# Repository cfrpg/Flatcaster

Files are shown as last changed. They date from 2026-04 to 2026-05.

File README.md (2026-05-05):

# Flatcaster

纯 PCB 实现的电容触摸吉他项目。

基于 AT32F435 主控，板载 AT-Link 下载器。采用 MAX98357A 功放输出，支持自校准电容矩阵触摸，可独立控制 6 根琴弦的拨动和 6 个品位，实现完整的弹奏体验。音色采用 Karplus-Strong 物理建模和 [Unreal Instruments](https://sfzinstruments.github.io/guitars/standard_guitar/) 的采样音源。包含网页上位机程序。

演示视频：[Bilibili](https://www.bilibili.com/video/BV1TAoMBCENc)

## 特性

- 纯 PCB 吉他结构
- AT32F435 主控 + 板载 AT-Link 下载器
- MAX98357A 功放输出
- 自校准电容矩阵触摸（6 根弦 + 6 个品位）
- Karplus-Strong 物理建模音色
- Unreal Instruments - Standard Guitar 音源
- 网页上位机程序

## 操作
### 基本操作
打开开关，LED红灯常亮，之后变为蓝色闪烁即可正常演奏。红色闪烁表示电池电量不足，请及时充电。

使用电位器调节音量。左侧6*7触摸区域为品位区，右侧长条触摸为拨弦区。

按**B**键切换模式。

### 演奏模式
开机后默认为演奏模式，LED为蓝色或绿色闪烁。

#### 校准触摸
如果触摸不灵，可以**长按A键**3秒以上松开，LED闪烁3次，完成触摸校准。

#### 切换音色
**短按A键**松开切换音色，LED蓝色闪烁为K-S音色，绿色闪烁为Unreal Instruments采样音源。

### 设置模式
在演奏模式下按**B**键进入设置模式，此时LED变为红色常亮。

设置完成后再次按**B**键使设置生效返回演奏模式。

#### 调整变调夹和移调

在品位区选择需要移动的半音数，**6弦1品**为移动**0个半音**，每增加一品**半音数+1**，每向上一条弦**半音数+6**。

按住的品位后，**拨动1弦**设置为移调数，**拨动6弦**设置为变调夹位置。

**拨动3弦或4弦**恢复初始设置。

LED闪烁3次表示设置生效，但重新开机后会恢复默认设置。

**eg：** 设置移调为2，变调夹为3，此时空弦变为原本的3品，1品变为原本的6品（1品+变调夹3+移调2）。

#### 保存参数

在设置模式下，**长按A键**3秒以上松开，LED闪烁5次，将设置保存到flash中，下次开机会保留当前的设置。

### 使用网页端上位机
下载src/Flatcaster.html到本地，使用USB线连接计算机，浏览器打开Flatcaster.html，点击连接串口，选择对应的串口连接。

### 常见问题

- 使用电池供电时可能会出现触摸不灵敏的情况，多次重新校准无效的情况下，可以尝试右手接触背面金属部分（如USB插座外壳或扬声器外壳），或连接USB线使用。

## 项目结构

```bash
Flatcaster/
├── doc/                # AT32引脚分配与仿真文件
├── pcb/                # 硬件设计
├── src/
│   ├── v0.1/           # AT32F435 固件源码
│   └── Flatcaster.html # 网页上位机
└── ...

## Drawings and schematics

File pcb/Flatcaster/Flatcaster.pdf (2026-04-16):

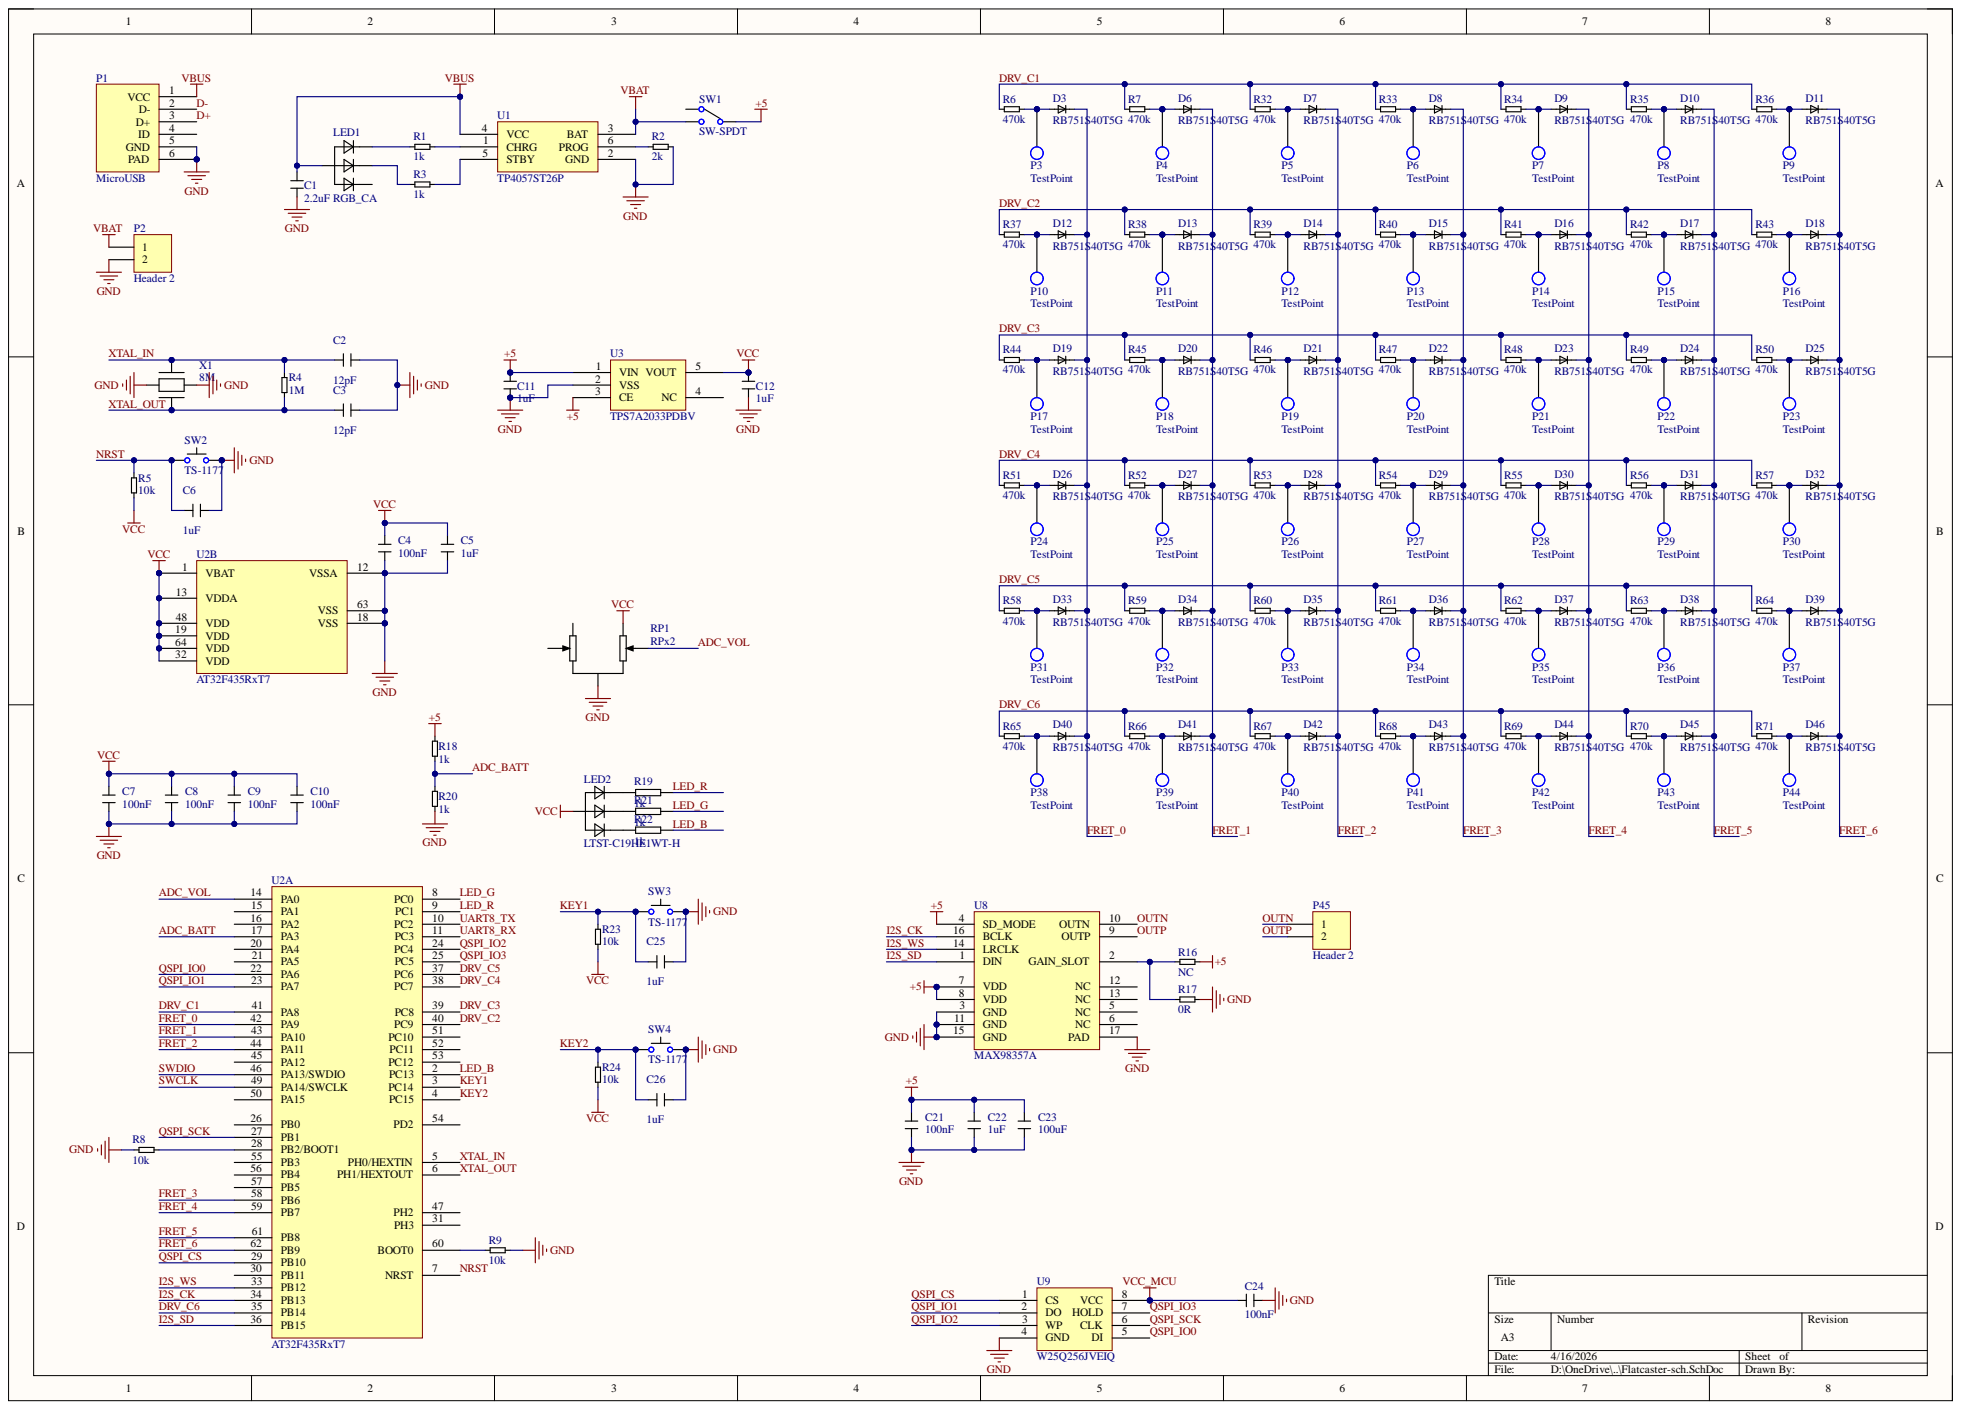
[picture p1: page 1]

VSS 2

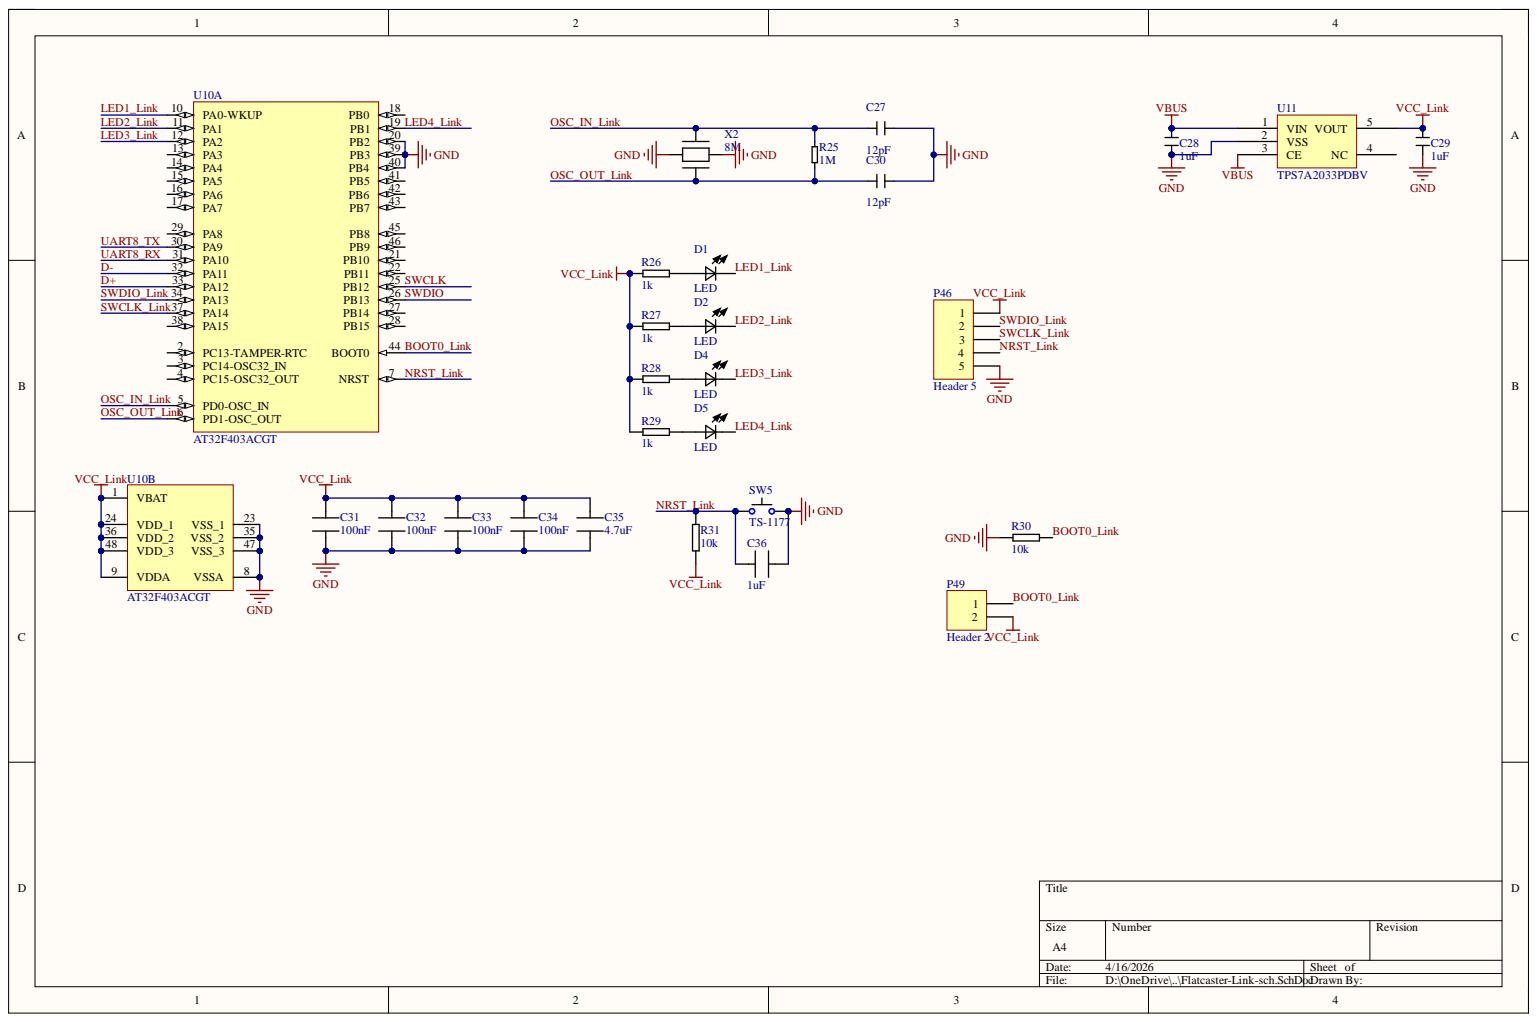
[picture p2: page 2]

3 6 | 3 5
4 8 | 4 7

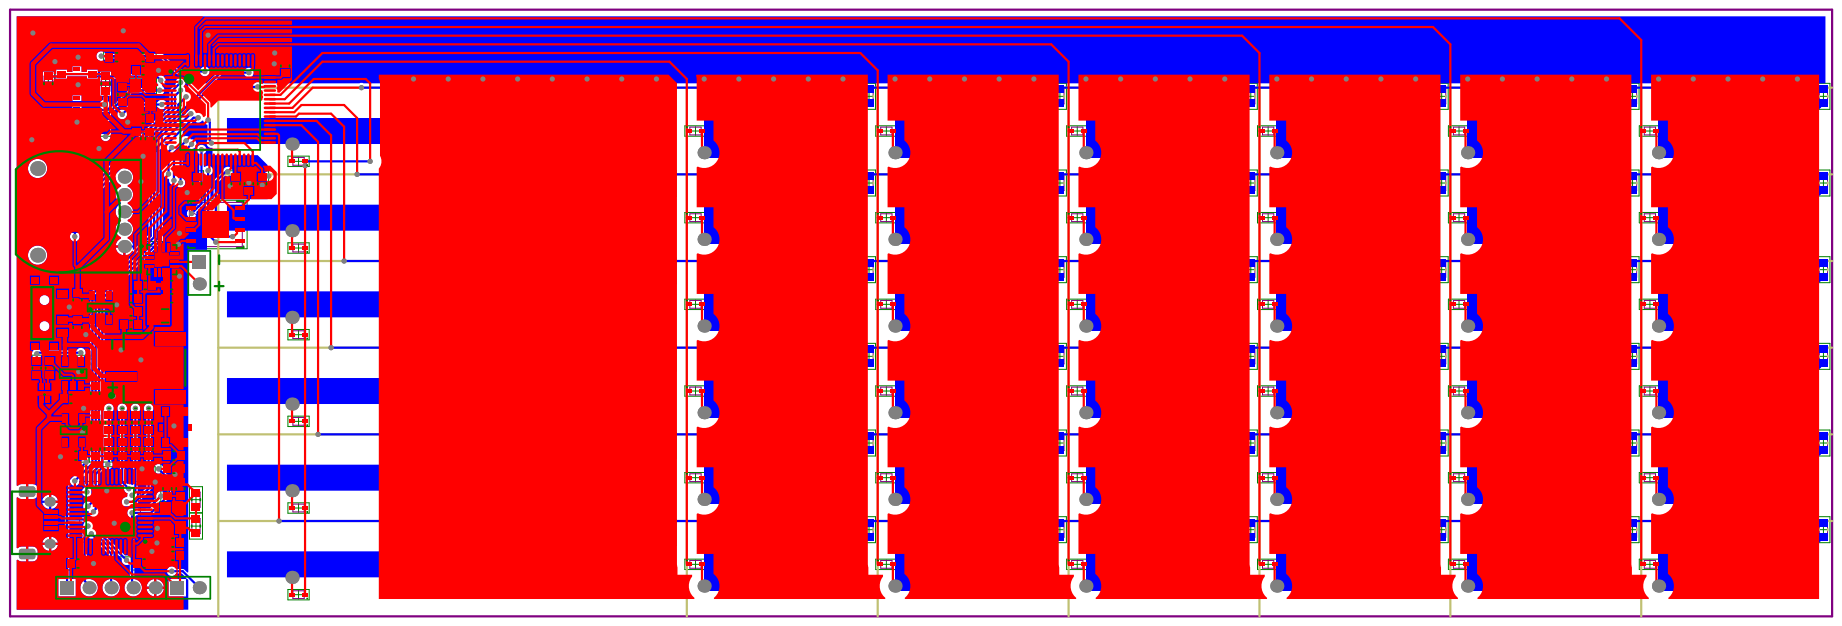
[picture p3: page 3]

Comment | Description | Designator | Footprint | LibRef | Quantity
2.2uF | | C1 | 0603-Cap | Cap | 1
12pF | | C2, C3, C27, C30 | 0603-Cap | Cap | 4
100nF | | C4, C7, C8, C9, C10, C21, C24, C31, C32, C33, C34 | 0603-Cap | Cap | 11
1uF | | C5, C6, C11, C12, C22, C25, C26, C28, C29, C36 | 0603-Cap | Cap | 10
100uF | | C23 | 1206-C | Cap | 1
4.7uF | | C35 | 0603-Cap | Cap | 1
LED | | D1, D2, D4, D5 | 0603-1 | LED | 4
RB751S40T5G | | D3, D6, D7, D8, D9, D10, D11, D12, D13, D14, D15, D16, D17, D18, D19, D20, D21, D22, D23, D24, D25, D26, D27, D28, D29, D30, D31, D32, D33, D34, D35, D36, D37, D38, D39, D40, D41, D42, D43, D44, D45, D46 | SOD-523 | Diode | 42
RGB_CA | | LED1 | RGB1.6*1.6 | RGB_CA | 1
LTST-C19HE1WT-H | C427425 | LED2 | RGB1.6*1.6 | RGB_CA | 1
MicroUSB | | P1 | MicroUSB | MicroUSB | 1
Header 2 | Header, 2-Pin | P2 | SH2.0 2P | Header 2 | 1
TestPoint | | P3, P4, P5, P6, P7, P8, P9, P10, P11, P12, P13, P14, P15, P16, P17, P18, P19, P20, P21, P22, P23, P24, P25, P26, P27, P28, P29, P30, P31, P32, P33, P34, P35, P36, P37, P38, P39, P40, P41, P42, P43, P44 | TestPoint | TestPoint | 42
Header 2 | Header, 2-Pin | P45, P49 | HDR1X2 | Header 2 | 2
Header 5 | Header, 5-Pin | P46 | HDR1X5 | Header 5 | 1
1k | | R1, R3, R18, R19, R20, R21, R22, R26, R27, R28, R29 | 0603 | Res | 11
2k | | R2 | 0603 | Res | 1
1M | | R4, R25 | 0603 | Res | 2
10k | | R5, R8, R9, R23, R24, R30, R31 | 0603 | Res | 7
470k | | R6, R7, R32, R33, R34, R35, R36, R37, R38, R39, R40, R41, R42, R43, R44, R45, R46, R47, R48, R49, R50, R51, R52, R53, R54, R55, R56, R57, R58, R59, R60, R61, R62, R63, R64, R65, R66, R67, R68, R69, R70, R71 | 0603 | Res | 42
NC | | R16 | 0603 | Res | 1
0R | | R17 | 0603 | Res | 1
RPx2 | | RP1 | RK10J | RPx2 | 1
SW-SPDT | C514014 | SW1 | TA-3524A-A1 | SW-SPDT | 1
TS-1177 | C561512 | SW2, SW3, SW4, SW5 | BTN3*3 | Btn | 4
TP4057ST26P | | U1 | SOT236 | TP4057ST26P | 1
AT32F435RxT7 | | U2 | LQFP-64 | AT32F435RxT7 | 1
TPS7A2033PDBV | | U3, U11 | SOT23-5 | ME6211 | 2
MAX98357A | | U8 | QFN16-0.5-1.1PAD | MAX98357A | 1
W25Q256JVEIQ | | U9 | WPDFN-8-6x5 | W25QxxxVE/A | 1
AT32F403ACGT | | U10 | STM-LQFP48_N | STM32F103CBT6 | 1
8M | C2682774 | X1, X2 | XTAL-3225-4P | XTAL-4LEAD | 2

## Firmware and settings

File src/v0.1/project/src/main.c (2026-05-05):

#include <stdio.h>
#include "sys.h"
#include "sys_config.h"
#include "delay.h"
#include "debug_usart.h"
#include "timer.h"
#include "led.h"
#include "parameter.h"
#include "pptlink.h"
#include "max98357a.h"
#include "signalGen.h"
#include "ks_engine.h"
#include "touch.h"
#include "midi.h"
#include "adc.h"
#include "norflash.h"
#include "instrument_data.h"
#include "mathHelper.h"
#include "spl_engine.h"
#include "keys.h"

#define STATE_PLAY	0
#define STATE_CALI	1
#define STATE_SET	2

void show_logo(void);

volatile u32 timecnt[4];

float freq_table[6][7];
u8 note_table[6][7];

KS_Engine my_guitar;
SPL_Engine spl_guitar;

s32 *capoPos;
s32 *fertShift;

float volume=0;
u8 low_batt=0;

u8 adc_ch=0;

u8 source=0;



u8 state=0;


void set_LED(void)
{
	if(low_batt==1)
	{
		LEDSetPattern(LED_2Hz,LED_OFF,LED_OFF);
	}
	else
	{
		if(state==STATE_PLAY)
		{
			if(source==0)
				LEDSetPattern(LED_OFF,LED_OFF,LED_1Hz);
			else
				LEDSetPattern(LED_OFF,LED_1Hz,LED_OFF);
		}
		if(state==STATE_SET)
		{
			LEDSetPattern(LED_ON,LED_OFF,LED_OFF);
		}
		
	}
}

void update_fert(void)
{
	for(u8 i=0;i<6;i++)
	{
		s32 idx=guitar_empty_string[i]+*capoPos;
		note_table[i][0]=idx;		
		for(u8 j=1;j<7;j++)
		{
			u8 real_fert=6-j+*fertShift+1;
			note_table[i][j]=idx+real_fert;			
		}
	}
	for(u8 i=0;i<6;i++)
	{
		for(u8 j=0;j<7;j++)
		{
			freq_table[i][j]=midi_frequencies[note_table[i][j]];
		}
	}	
}

int main(void)
{  
	SystemConfigInit();
	DelayInit(288000000);
	DebugUSARTInit(2000000);
	MainClockInit();
	ParamInit();
	
	// Init hardware drivers
	LEDInit();
	LEDSetRGB(0,1,1);
	LEDSetPattern(LED_OFF,LED_OFF,LED_1Hz);
	KeysInit();
	
	ADCInit();
	TouchInit();
	MAX98357AInit();
	FlashInit();	
	FlashXIPInit();
	
	// Init software modules
	ks_init(&my_guitar,48000);
	SPL_Init(&spl_guitar,&UI_guitar);
	u32 cnt=0;	
	u8 output=0;

	
	
	// Init freq table	
	capoPos=ParamGetFromName("CAPO_POS");
	fertShift=ParamGetFromName("FERT_SHIFT");
	update_fert();
	
	// Check vol
	ADCStartChannel(adc_ch);
	
	// Calibration
	LED_R=0;
	TouchScan();
	delay_ms(1000);
	TouchSetRef();
	LED_R=1;
	show_logo();
	
//	while(1);
	
	while(1)
	{
		// 10Hz update
		if(timecnt[0]>=10000)
		{
			timecnt[0]=0;
			LEDUpdate();
			if(adc_ch==0)
			{
				// vol data
				u16 vol=ADCReadOut()>>4;
				volume=vol*1.0f/256;
				adc_ch=3;
				
			}
			else if(adc_ch==3)
			{
				// batt data
				float volt=ADCReadVolt()*2;
				if(low_batt==0 && volt<3.68f)
				{
					low_batt=1;
					set_LED();
				}
				if(low_batt==1 && volt>3.68f)
				{
					low_batt=0;
					set_LED();
				}
				adc_ch=0;
				
			}
			ADCStartChannel(adc_ch);
			printf("FERT:%d,%d\r\n",*capoPos,*fertShift);
			
			// check keys
			KeysUpdate();
			if((KeyStatus[0]&0x01)==0)
			{
				if((KeyStatus[0])==0xFFFFFFFE)
				{	
					if(state==STATE_PLAY)
					{
						TouchSetRef();					
						LEDFlash(3);
					}
					else if(state==STATE_SET)
					{
						ParamWrite();
						LEDFlash(5);
					}
					
				}
				else if((KeyStatus[0]&0x1E)==0x1E)
				{
					if(state==STATE_PLAY)
					{
						source^=1;
						set_LED();
					}
					else if(state==STATE_SET)
					{
						
					}
					
				}			
			}
			
			
		}
		// 50Hz update
		if(timecnt[1]>=2000)
		{
			timecnt[1]=0;
			
			if(output==0)
			{
				printf("DATA:");
				for(u32 i=0;i<6;i++)
				{
					for(u32 j=0;j<8;j++)
					{					
						printf("%d,",touch.rawData[i][j]);					
					}
				}
			}
			else
			{
				printf("REF:");
				for(u32 i=0;i<6;i++)
				{
					for(u32 j=0;j<8;j++)
					{					
						printf("%d,",touch.refData[i][j]);					
					}
				}
			}			
			printf("\r\n");
			output^=1;
		}
		// 1000Hz update
		if(timecnt[2]>=100)
		{
			timecnt[2]=0;
			// get input
			TouchGetKey();
			
			if(state==STATE_PLAY)
			{
				// trigger note
				for(u8 str=0;str<6;str++)
				{
					if((touch.stringState[str]&0xFF)==0xF)
					{
						u8 note=note_table[str][touch.stringFert[str]];
						if(source==0)
						{
							stop_string_soft(&my_guitar.strings[str]);
							trig_note(&my_guitar,str,midi_frequencies[note],0.992f,0.2f);
						}
						else
						{
							SPL_Trig_note(&spl_guitar,str,note);
						}
						
						printf("TRIG:%d,%d,%d\r\n",str,touch.stringFert[str]==0?0:7-touch.stringFert[str],note);
					}
				}
				
				if(audioState.data_required!=0)
				{
					u32 pos=0;
					
					if(audioState.data_required==2)
						pos=I2S_BUF_SIZE;
					if(source==0)
					{
						for(u32 i=0;i<I2S_BUF_SIZE;i+=2)
						{
							float out=0;
							for(u32 j=0;j<6;j++)
							{
								out+=(update_string(&my_guitar.strings[j])*32768.0f)/6;
							}
							audioState.buff[i+pos]=(s16)(out*volume);
							audioState.buff[i+pos+1]=audioState.buff[i+pos];
						}
					}
					else
					{
						SPL_UpdateBuff(&spl_guitar);
						for(u32 i=0;i<I2S_BUF_SIZE;i+=2)
						{
							float out=0;
							for(u32 j=0;j<6;j++)
							{
								if(spl_guitar.strings[j].active>=0)
								{
									out+=((float)spl_guitar.strings[j].buff[i/2]);
								}						
							}
							out=Clampf(out/2*volume,-32767,32767);
							audioState.buff[i+pos]=(s16)(out*volume);
							audioState.buff[i+pos+1]=audioState.buff[i+pos];
						}
					}
					audioState.data_required=0;
				}
				if((KeyStatus[1]&0xFF)==0x0F)
				{
					state=STATE_SET;
					memset(audioState.buff,0,sizeof(audioState.buff));
					set_LED();
				}
			}
			else if(state==STATE_SET)
			{				
				u32 shift=0;
				// set capo & shift
				for(u8 str=5;str>=2;str--)
				{
					if(touch.stringFert[str]!=0)
					{
						shift=(5-str)*6+(6-touch.stringFert[str]);
						break;
					}
				}
				
				if((touch.stringState[0]&0x3F)==1)
				{
					// set capo
					*capoPos=shift;
					LEDFlash(3);
				}
				else if((touch.stringState[5]&0x3F)==1)
				{
					// set shift
					*fertShift=shift;
					LEDFlash(3);
				}
				else if(((touch.stringState[3]&0x3F)==1)||((touch.stringState[2]&0x3F)==1))
				{
					//reset
					*capoPos=0;
					*fertShift=0;
					LEDFlash(3);
				}
				
				if((KeyStatus[1]&0xFF)==0x0F)
				{
					state=STATE_PLAY;
					update_fert();
					set_LED();
				}
				
			}			
//			printf("%d\r\n",timecnt[2]);
		}
		// Slow work, 1Hz
		if(timecnt[3]>=100000)
		{
			timecnt[3]=0;
			
			if(debug_cmd_ready == 1)
			{
				//ppt link
				DebugUSARTGetCmd();
				AnalyzePkg(debug_cmd_buff, debug_cmd_length);
				debug_cmd_ready=0;
			}			
		}		
	}
}

void TMR1_BRK_TMR9_IRQHandler(void)
{
	u8 i;
	if(tmr_interrupt_flag_get(TMR9,TMR_OVF_FLAG)!=RESET)
	{
		tmr_flag_clear(TMR9,TMR_OVF_FLAG);
		for(i=0;i<4;i++)
		{
			timecnt[i]++;
		}
	}
}

void show_logo(void)
{	
	printf("___________.__          __                          __                \r\n");
	printf("\\_   _____/|  | _____ _/  |_  ____ _____    _______/  |_  ___________ \r\n");
	printf(" |    __)  |  | \\__  \\\\   __\\/ ___\\\\__  \\  /  ___/\\   __\\/ __ \\_  __ \\ \r\n");
	printf(" |     \\   |  |__/ __ \\|  | \\  \\___ / __ \\_\\___ \\  |  | \\  ___/|  | \\/ \r\n");
	printf(" \\___  /   |____(____  /__|  \\___  >____  /____  > |__|  \\___  >__|   \r\n");
	printf("     \\/              \\/          \\/     \\/     \\/            \\/       \r\n");
}

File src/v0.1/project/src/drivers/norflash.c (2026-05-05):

#include "norflash.h"
#include "qspicmd.h"
#include "delay.h"

qspi_cmd_type QSPI_WREN;
qspi_cmd_type QSPI_EN4B;
qspi_cmd_type QSPI_RDSR;
qspi_cmd_type QSPI_READ;
qspi_cmd_type QSPI_WRITE;
qspi_cmd_type QSPI_ERASE;

qspi_cmd_type QSPI_CMD;


void flash_gpio_init(void)
{
	gpio_init_type gpio_init_struct;
	gpio_default_para_init(&gpio_init_struct);
	
	crm_periph_clock_enable(CRM_GPIOA_PERIPH_CLOCK, TRUE);
	crm_periph_clock_enable(CRM_GPIOB_PERIPH_CLOCK, TRUE);
	crm_periph_clock_enable(CRM_GPIOC_PERIPH_CLOCK, TRUE);
	
	/* configure the SCK pin */
	gpio_pin_mux_config(QSPI_SCK_GPIO_PORT, GPIO_PINS_SOURCE1, GPIO_MUX_9);
	gpio_init_struct.gpio_drive_strength = GPIO_DRIVE_STRENGTH_STRONGER;
	gpio_init_struct.gpio_out_type = GPIO_OUTPUT_PUSH_PULL;
	gpio_init_struct.gpio_mode = GPIO_MODE_MUX;
	gpio_init_struct.gpio_pins = QSPI_SCK_PIN;
	gpio_init_struct.gpio_pull = GPIO_PULL_NONE;
	gpio_init(QSPI_SCK_GPIO_PORT, &gpio_init_struct);

	/* configure the CS pin */
	gpio_pin_mux_config(QSPI1_CS_GPIO_PORT, GPIO_PINS_SOURCE10, GPIO_MUX_9);
	gpio_init_struct.gpio_drive_strength = GPIO_DRIVE_STRENGTH_STRONGER;
	gpio_init_struct.gpio_out_type = GPIO_OUTPUT_PUSH_PULL;
	gpio_init_struct.gpio_mode = GPIO_MODE_MUX;
	gpio_init_struct.gpio_pins = QSPI1_CS_PIN;
	gpio_init_struct.gpio_pull = GPIO_PULL_NONE;
	gpio_init(QSPI1_CS_GPIO_PORT, &gpio_init_struct);

	/* configure the IO0 pin */
	gpio_pin_mux_config(QSPI_IO0_GPIO_PORT, GPIO_PINS_SOURCE6, GPIO_MUX_10);
	gpio_init_struct.gpio_drive_strength = GPIO_DRIVE_STRENGTH_STRONGER;
	gpio_init_struct.gpio_out_type = GPIO_OUTPUT_PUSH_PULL;
	gpio_init_struct.gpio_mode = GPIO_MODE_MUX;
	gpio_init_struct.gpio_pins = QSPI_IO0_PIN;
	gpio_init_struct.gpio_pull = GPIO_PULL_NONE;
	gpio_init(QSPI_IO0_GPIO_PORT, &gpio_init_struct);

	/* configure the IO1 pin */
	gpio_pin_mux_config(QSPI_IO1_GPIO_PORT, GPIO_PINS_SOURCE7, GPIO_MUX_10);
	gpio_init_struct.gpio_drive_strength = GPIO_DRIVE_STRENGTH_STRONGER;
	gpio_init_struct.gpio_out_type = GPIO_OUTPUT_PUSH_PULL;
	gpio_init_struct.gpio_mode = GPIO_MODE_MUX;
	gpio_init_struct.gpio_pins = QSPI_IO1_PIN;
	gpio_init_struct.gpio_pull = GPIO_PULL_NONE;
	gpio_init(QSPI_IO1_GPIO_PORT, &gpio_init_struct);

	/* configure the IO2 pin */
	gpio_pin_mux_config(QSPI_IO2_GPIO_PORT, GPIO_PINS_SOURCE4, GPIO_MUX_10);
	gpio_init_struct.gpio_drive_strength = GPIO_DRIVE_STRENGTH_STRONGER;
	gpio_init_struct.gpio_out_type = GPIO_OUTPUT_PUSH_PULL;
	gpio_init_struct.gpio_mode = GPIO_MODE_MUX;
	gpio_init_struct.gpio_pins = QSPI_IO2_PIN;
	gpio_init_struct.gpio_pull = GPIO_PULL_NONE;
	gpio_init(QSPI_IO2_GPIO_PORT, &gpio_init_struct);

	/* configure the IO3 pin */
	gpio_pin_mux_config(QSPI_IO3_GPIO_PORT, GPIO_PINS_SOURCE5, GPIO_MUX_10);
	gpio_init_struct.gpio_drive_strength = GPIO_DRIVE_STRENGTH_STRONGER;
	gpio_init_struct.gpio_out_type = GPIO_OUTPUT_PUSH_PULL;
	gpio_init_struct.gpio_mode = GPIO_MODE_MUX;
	gpio_init_struct.gpio_pins = QSPI_IO3_PIN;
	gpio_init_struct.gpio_pull = GPIO_PULL_NONE;
	gpio_init(QSPI_IO3_GPIO_PORT, &gpio_init_struct);
}

void show_cmd_reg(void)
{
	printf("W0:%08x\r\n",QSPI1->cmd_w0);
	printf("W1:%08x\r\n",QSPI1->cmd_w1);
	printf("W2:%08x\r\n",QSPI1->cmd_w2);
	printf("W3:%08x\r\n",QSPI1->cmd_w3);
}

void flash_qspi_init(void)
{
	crm_periph_clock_enable(CRM_QSPI1_PERIPH_CLOCK, TRUE);
	
	qspi_xip_enable(QSPI1, FALSE);
	qspi_clk_division_set(QSPI1, QSPI_CLK_DIV_8);
	qspi_sck_mode_set(QSPI1, QSPI_SCK_MODE_0);
	qspi_busy_config(QSPI1, QSPI_BUSY_OFFSET_0);
	qspi_auto_ispc_enable(QSPI1);
	
	//Init cmd struct
	qspi_cmd_wren_config(&QSPI_WREN);
	qspi_cmd_en4b_config(&QSPI_EN4B);
	qspi_cmd_rdsr_config(&QSPI_RDSR);
	
	qspi_cmd_read_config(&QSPI_READ,0,0);
	qspi_cmd_write_config(&QSPI_WRITE,0,0);
	qspi_cmd_erase_config(&QSPI_ERASE,0);	
}

void flash_cmd_send(qspi_cmd_type* cmd)
{
	qspi_cmd_operation_kick(QSPI1, cmd);

	/* wait command completed */
	while(qspi_flag_get(QSPI1, QSPI_CMDSTS_FLAG) == RESET);
	qspi_flag_clear(QSPI1, QSPI_CMDSTS_FLAG);
}

void flash_write_enable(void)
{
	flash_cmd_send(&QSPI_WREN);	
}

void flash_busy_check(void)
{
	flash_cmd_send(&QSPI_RDSR);	
}

void flash_write_status(u8 data)
{
	flash_write_enable();
	
	qspi_cmd_wrsr_config(&QSPI_CMD);
	QSPI_CMD.instruction_code=0x31;
	qspi_cmd_operation_kick(QSPI1,&QSPI_CMD);
	while(qspi_flag_get(QSPI1, QSPI_TXFIFORDY_FLAG) == RESET);
	qspi_byte_write(QSPI1, data);
	while(qspi_flag_get(QSPI1, QSPI_CMDSTS_FLAG) == RESET);
	qspi_flag_clear(QSPI1, QSPI_CMDSTS_FLAG);
}

void flash_read_status(void)
{
	u8 data;
	qspi_cmd_rdsr2_config(&QSPI_CMD,0x05);
	qspi_cmd_operation_kick(QSPI1,&QSPI_CMD);	
	while(qspi_flag_get(QSPI1, QSPI_RXFIFORDY_FLAG) == RESET);
	data=qspi_byte_read(QSPI1);
	while(qspi_flag_get(QSPI1, QSPI_CMDSTS_FLAG) == RESET);
	qspi_flag_clear(QSPI1, QSPI_CMDSTS_FLAG);
	printf("ST1:%x\r\n",data);
	
	
	qspi_cmd_rdsr2_config(&QSPI_CMD,0x35);
	qspi_cmd_operation_kick(QSPI1,&QSPI_CMD);	
	while(qspi_flag_get(QSPI1, QSPI_RXFIFORDY_FLAG) == RESET);
	data=qspi_byte_read(QSPI1);
	while(qspi_flag_get(QSPI1, QSPI_CMDSTS_FLAG) == RESET);
	qspi_flag_clear(QSPI1, QSPI_CMDSTS_FLAG);
	printf("ST2:%x\r\n",data);
	
	qspi_cmd_rdsr2_config(&QSPI_CMD,0x15);
	qspi_cmd_operation_kick(QSPI1,&QSPI_CMD);	
	while(qspi_flag_get(QSPI1, QSPI_RXFIFORDY_FLAG) == RESET);
	data=qspi_byte_read(QSPI1);
	while(qspi_flag_get(QSPI1, QSPI_CMDSTS_FLAG) == RESET);
	qspi_flag_clear(QSPI1, QSPI_CMDSTS_FLAG);
	printf("ST3:%x\r\n",data);
}


void flash_read_id(void)
{
	qspi_cmd_rdid_config(&QSPI_CMD);
	qspi_cmd_operation_kick(QSPI1,&QSPI_CMD);
	u8 data[3];
	while(qspi_flag_get(QSPI1, QSPI_RXFIFORDY_FLAG) == RESET);
	for(u8 i=0;i<3;i++)
	{
		
		data[i] = qspi_byte_read(QSPI1);
	}
	
	while(qspi_flag_get(QSPI1, QSPI_CMDSTS_FLAG) == RESET);
	qspi_flag_clear(QSPI1, QSPI_CMDSTS_FLAG);
	printf("id:%x %x %x\r\n",data[0],data[1],data[2]);
}

void flash_set_4byte_addr(void)
{
	qspi_cmd_en4b_config(&QSPI_CMD);
	qspi_cmd_operation_kick(QSPI1,&QSPI_CMD);

	while(qspi_flag_get(QSPI1, QSPI_CMDSTS_FLAG) == RESET);
	qspi_flag_clear(QSPI1, QSPI_CMDSTS_FLAG);
}

void FlashInit(void)
{
	flash_gpio_init();
	flash_qspi_init();
	delay_ms(1);
	flash_busy_check();
	
//	flash_read_status();	
	flash_set_4byte_addr();
	flash_write_status(0x02);
//	flash_read_status();
}

void FlashEarse(u32 addr)
{
	flash_write_enable();
	
	QSPI_ERASE.address_code=addr;
	flash_cmd_send(&QSPI_ERASE);
	flash_busy_check();
}

void FlashWrite(u32 addr, u8* buff, u32 len)
{
	flash_write_enable();
	qspi_cmd_write_config(&QSPI_WRITE,addr,len);
	qspi_cmd_operation_kick(QSPI1,&QSPI_WRITE);
	show_cmd_reg();
	for(u16 i=0;i<len;i++)
	{
		while(qspi_flag_get(QSPI1, QSPI_TXFIFORDY_FLAG) == RESET);
		qspi_byte_write(QSPI1, *buff++);
	}	
	
	while(qspi_flag_get(QSPI1, QSPI_CMDSTS_FLAG) == RESET);
	qspi_flag_clear(QSPI1, QSPI_CMDSTS_FLAG);

	flash_busy_check();
}
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

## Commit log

2026-04-15 Add PCB.
    [Flatcaster-Link-sch.SchDoc, Flatcaster-pcb.PcbDoc, Flatcaster-sch.SchDoc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]
2026-04-15 Add pdf.
    [Flatcaster.PrjPcb]
2026-04-16 Remove obsoleted MPR121.
    [Flatcaster-Link-sch.SchDoc, Flatcaster-pcb.PcbDoc, Flatcaster-sch.SchDoc]
2026-04-23 Add some function.
    [Flatcaster-pcb.PcbDoc]
2026-04-27 Add round corner.
    [Flatcaster-pcb.PcbDoc]
2026-04-27 Add sampled source.
2026-04-27 Add capo & fert shift.
    [Flatcaster-pcb.PcbDoc]
